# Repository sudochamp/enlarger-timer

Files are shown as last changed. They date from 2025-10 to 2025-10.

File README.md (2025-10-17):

> [!WARNING]
> This project is a work in progress. It functions, but not where I want it yet.

# Darkroom Enlarger Timer

Built to address a simple problem. I just needed a simple timer that could do stop calculations and was accurate enough to be used in a darkroom.

It will need an off-the-shelf AC/DC power supply for the 120/240VAC to 12VDC conversion.

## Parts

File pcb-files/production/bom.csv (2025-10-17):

Designator | Footprint | Quantity | Value | LCSC Part #
C1, C11, C12, C5, C6, C7, C8 | 0603 | 7 | 100n
C10, C9 | 0603 | 2 | 10n
C13 | CP_Elec_4x5.4 | 1 | 10u
C2 | 0603 | 1 | 10u
C3 | 0603 | 1 | 100n | C1525
C4 | 0603 | 1 | 4.7u | C1779
H1, H2, H3, H4 | MountingHole_3.2mm_M3 | 4 | MountingHole
J1 | JST_VH_B2P-VH_1x02_P3.96mm_Vertical | 1 | PWR
J2 | PinHeader_1x04_P2.54mm_Vertical | 1 | SWD
J3 | JST_XH_B3B-XH-A_1x03_P2.50mm_Vertical | 1 | RELAY
R1, R2, R3, R6 | 0603 | 4 | 1k
R4, R5 | 0603 | 2 | 10k
R7 | 0603 | 1 | 51k
SW1 | SW_Kailh_Choc_V2_THT_nSilk | 1 | STOP+
SW2 | SW_Kailh_Choc_V2_THT_nSilk | 1 | STOP-
SW3 | RotaryEncoder_Alps_EC11E-Switch_Vertical_H20mm | 1 | EXPOSURE_TIME
SW4 | SW_Kailh_Choc_V2_THT_nSilk | 1 | TOGGLE
SW5 | Switch_Toggle_SPDT_SubMini | 1 | SW_SPDT
U1 | SOT-223-3_TabPin2 | 1 | LD1117S33TR_SOT223
U2 | LQFP-32_7x7mm_P0.8mm | 1 | STM32C031K6Tx
U3, U4, U5, U6 | SC10-21SURKWA | 4 | SC10-21SURKWA
U7 | SOIC-24W_7.5x15.4mm_P1.27mm | 1 | MAX7221

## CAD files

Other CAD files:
pcb-files/timer_v2.dxf

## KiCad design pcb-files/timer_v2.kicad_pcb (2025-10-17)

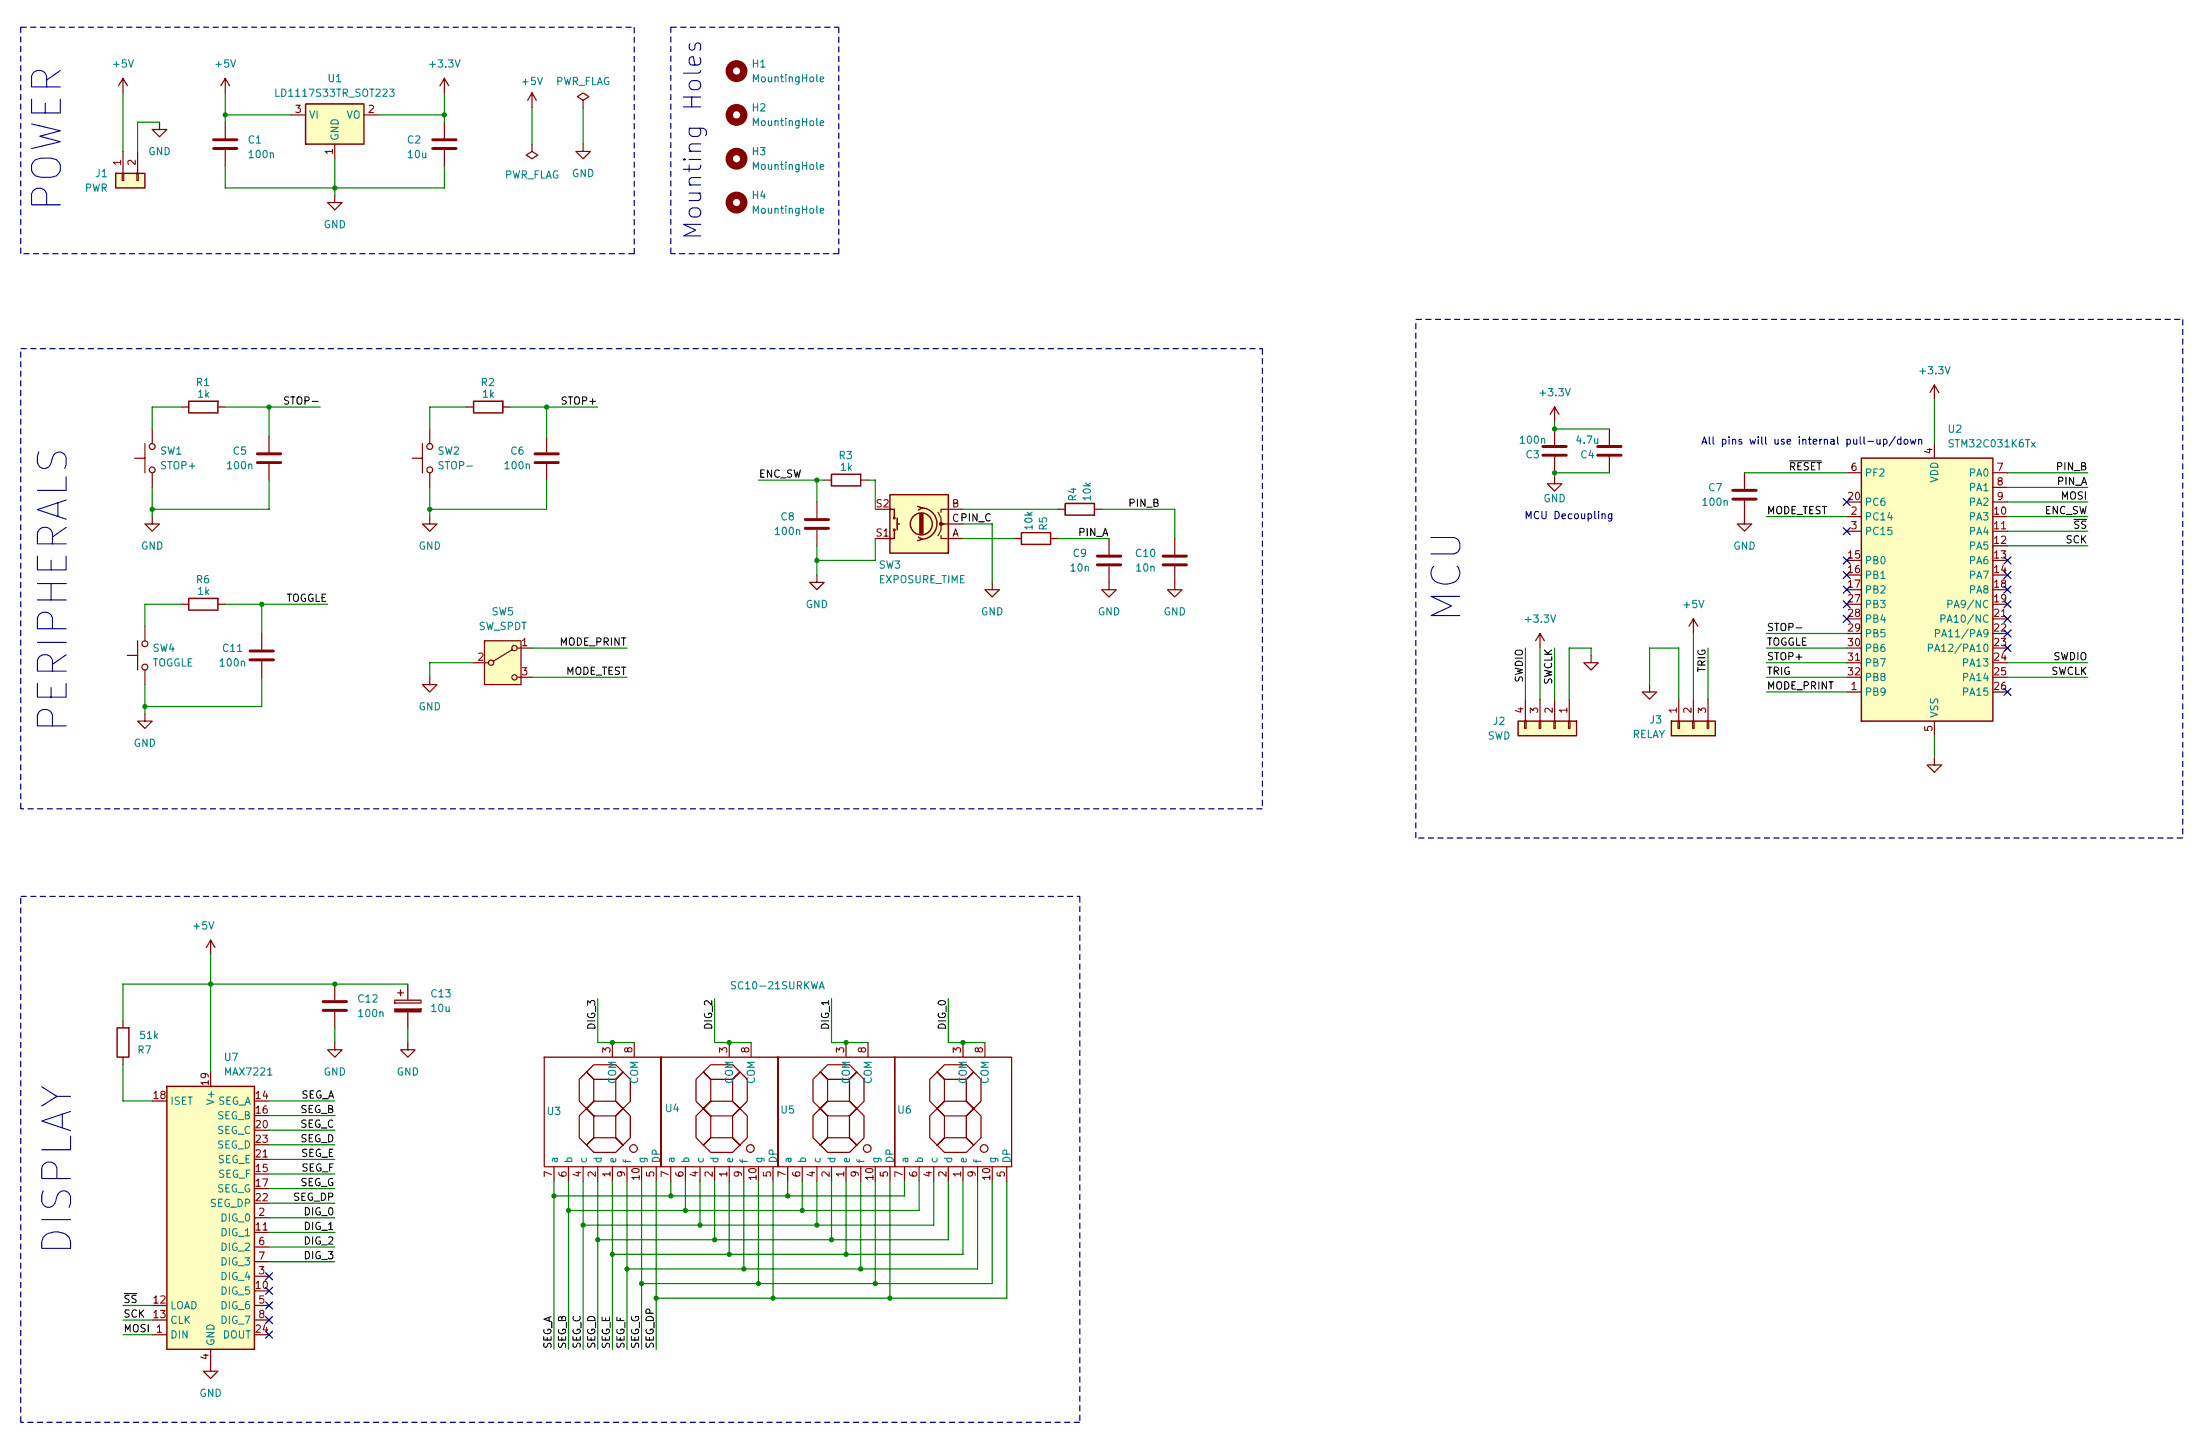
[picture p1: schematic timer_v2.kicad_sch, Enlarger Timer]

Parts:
C1, C8: 100n; C_0603_1608Metric; LCSC Part Number C5299898
C2: 10u; C_0603_1608Metric; LCSC Part Number C5299898
C3: 100n; C_0603_1608Metric; LCSC Part # C1525
C4: 4.7u; C_0603_1608Metric; LCSC Part # C1779
C5, C6, C7, C11, C12: 100n; C_0603_1608Metric; LCSC Part Number C2687355
C9, C10: 10n; C_0603_1608Metric; LCSC Part Number C5299898
C13: 10u; CP_Elec_4x5.4; LCSC Part Number C4747971
H1, H2, H3, H4: MountingHole; MountingHole_3.2mm_M3
J1: PWR; JST_VH_B2P-VH_1x02_P3.96mm_Vertical; LCSC Part Number C158007
J2: SWD; PinHeader_1x04_P2.54mm_Vertical
J3: RELAY; JST_XH_B3B-XH-A_1x03_P2.50mm_Vertical; LCSC Part Number C158007
R1, R2, R3, R6: 1k; R_0603_1608Metric; LCSC Part Number C5123581
R4, R5: 10k; R_0603_1608Metric; LCSC Part Number C5123581
R7: 51k; R_0603_1608Metric; LCSC Part Number C5355236
SW1: STOP+; SW_Kailh_Choc_V2_THT_nSilk; JLCPCB_Footprint SW_Kailh_Choc_V1V2_1.00u
SW2: STOP-; SW_Kailh_Choc_V2_THT_nSilk; JLCPCB_Footprint SW_Kailh_Choc_V1V2_1.00u
SW3: EXPOSURE_TIME; RotaryEncoder_Alps_EC11E-Switch_Vertical_H20mm; JLCPCB_Footprint RotaryEncoder_Alps_EC11E-Switch_Vertica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
SW4: TOGGLE; SW_Kailh_Choc_V2_THT_nSilk; JLCPCB_Footprint SW_Kailh_Choc_V1V2_1.00u
SW5: SW_SPDT; Switch_Toggle_SPDT_SubMini; JLCPCB_Footprint Switch_Toggle_SPDT_Mini_SolderLug
U1: LD1117S33TR_SOT223; SOT-223-3_TabPin2; JLCPCB_Footprint SOT-223-3_TabPin2
U2: STM32C031K6Tx; LQFP-32_7x7mm_P0.8mm; JLCPCB_Footprint LQFP-32_7x7mm_P0.8mm
U3, U4, U5, U6: SC10-21SURKWA
U7: MAX7221; SOIC-24W_7.5x15.4mm_P1.27mm; LCSC Part Number C6705351

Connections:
+3.3V: C2.1, C3.2, C4.2, J2.3, U1.2 (VO), U2.4 (VDD)
+5V: C1.1, C12.1, C13.1, J1.1, J3.2, R7.2, U1.3 (VI), U7.19 (V+)
/DIG_0: U6.3 (COM), U6.8 (COM), U7.2 (DIG_0)
/DIG_1: U5.3 (COM), U5.8 (COM), U7.11 (DIG_1)
/DIG_2: U4.3 (COM), U4.8 (COM), U7.6 (DIG_2)
/DIG_3: U3.3 (COM), U3.8 (COM), U7.7 (DIG_3)
/ENC_SW: C8.2, R3.1, U2.10 (PA3)
/MODE_PRINT: SW5.1 (A), U2.1 (PB9)
/MODE_TEST: SW5.3 (C), U2.2 (PC14)
/MOSI: U2.9 (PA2), U7.1 (DIN)
/PIN_A: C9.2, R5.1, U2.8 (PA1)
/PIN_B: C10.2, R4.2, U2.7 (PA0)
/SCK: U2.12 (PA5), U7.13 (CLK)
/SEG_A: U3.7 (a), U4.7 (a), U5.7 (a), U6.7 (a), U7.14 (SEG_A)
/SEG_B: U3.6 (b), U4.6 (b), U5.6 (b), U6.6 (b), U7.16 (SEG_B)
/SEG_C: U3.4 (c), U4.4 (c), U5.4 (c), U6.4 (c), U7.20 (SEG_C)
/SEG_D: U3.2 (d), U4.2 (d), U5.2 (d), U6.2 (d), U7.23 (SEG_D)
/SEG_DP: U3.5 (DP), U4.5 (DP), U5.5 (DP), U6.5 (DP), U7.22 (SEG_DP)
/SEG_E: U3.1 (e), U4.1 (e), U5.1 (e), U6.1 (e), U7.21 (SEG_E)
/SEG_F: U3.9 (f), U4.9 (f), U5.9 (f), U6.9 (f), U7.15 (SEG_F)
/SEG_G: U3.10 (g), U4.10 (g), U5.10 (g), U6.10 (g), U7.17 (SEG_G)
/STOP+: C6.2, R2.2, U2.31 (PB7)
/STOP-: C5.2, R1.2, U2.29 (PB5)
/SWCLK: J2.2, U2.25 (PA14)
/SWDIO: J2.4, U2.24 (PA13)
/TOGGLE: C11.2, R6.2, U2.30 (PB6)
/TRIG: J3.3, U2.32 (PB8)
/~RESET: C7.2, U2.6 (PF2)
/~SS: U2.11 (PA4), U7.12 (LOAD)
GND: C1.2, C2.2, C3.1, C4.1, C5.1, C6.1, C7.1, C8.1, C9.1, C10.1, C11.1, C12.2, C13.2, J1.2, J2.1, J3.1, SW1.1, SW2.1, SW3.C, SW3.S1, SW4.1, SW5.2 (B), U1.1 (GND), U2.5 (VSS), U7.4 (GND), U7.9 (GND)
unnamed: R1.1, SW1.2
unnamed: R2.1, SW2.2
unnamed: R3.2, SW3.S2
unnamed: R4.1, SW3.B
unnamed: R5.2, SW3.A
unnamed: R6.1, SW4.2
unnamed: R7.1, U7.18 (ISET)

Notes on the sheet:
MCU
MCU Decoupling
Mounting Holes
POWER
All pins will use internal pull-up/down
DISPLAY
PERIPHERALS

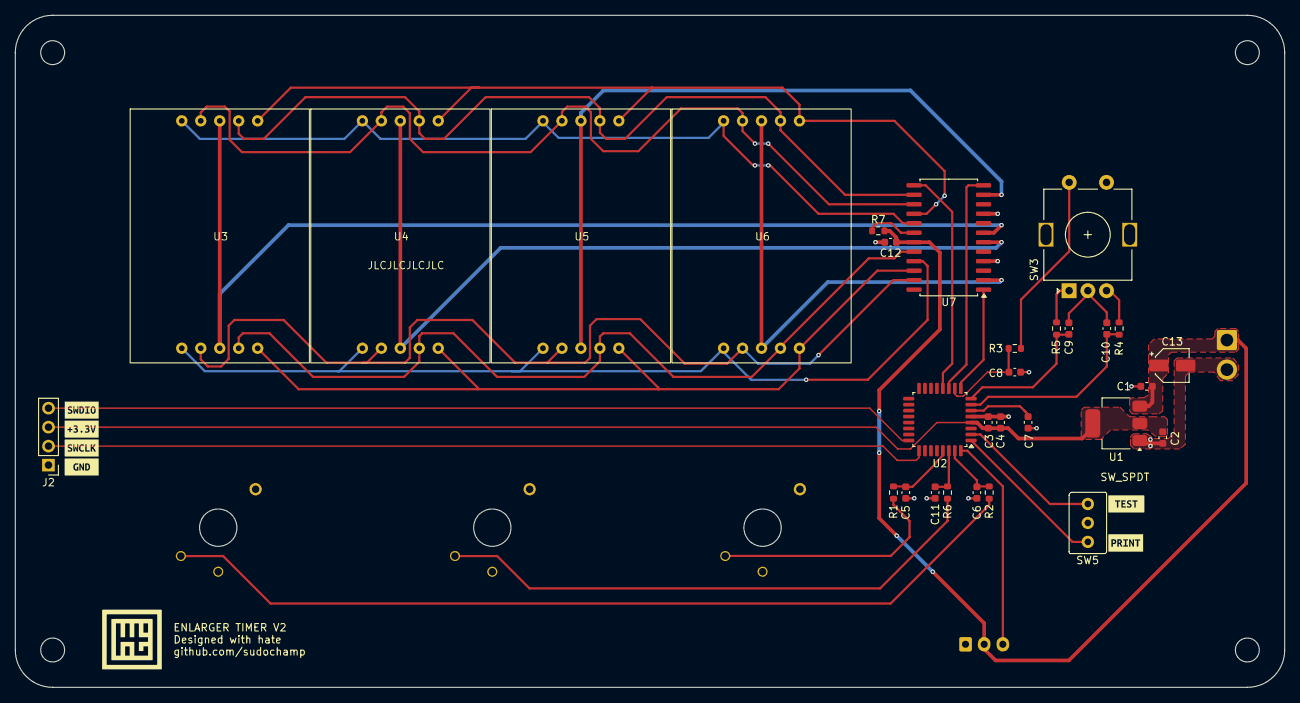
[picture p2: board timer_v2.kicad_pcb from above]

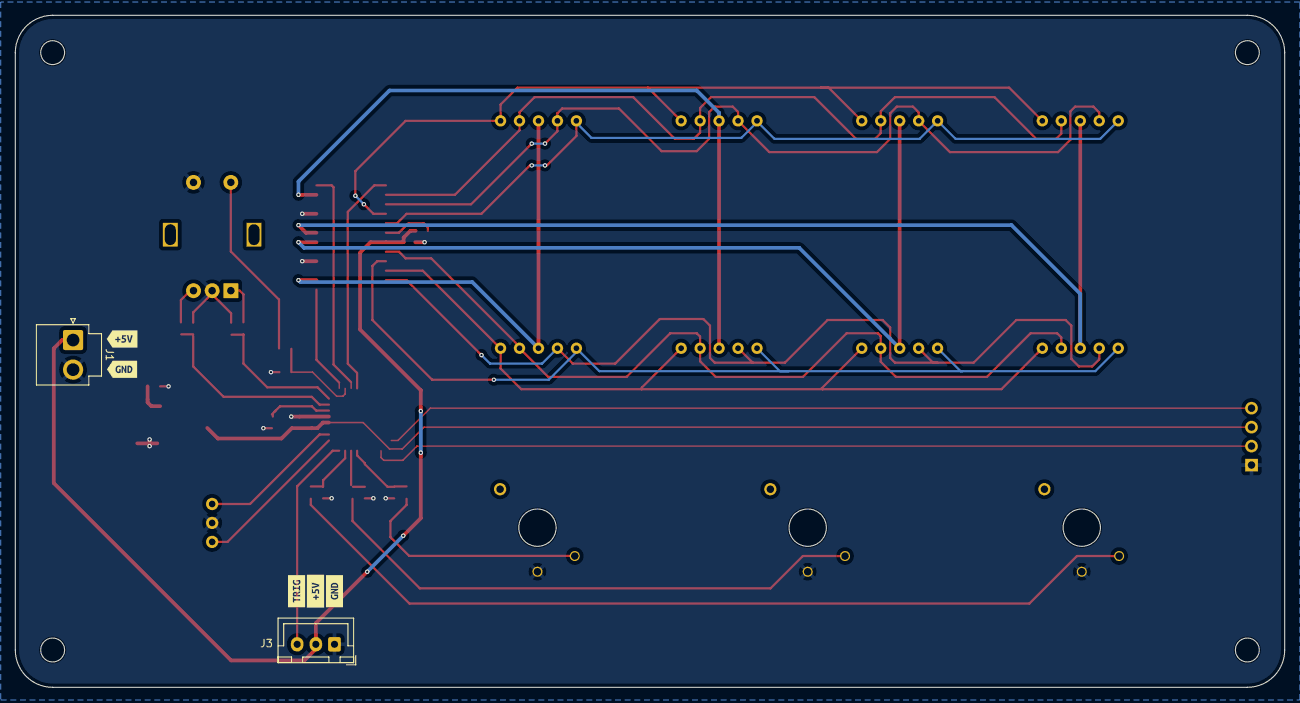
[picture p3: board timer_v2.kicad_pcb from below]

Board: 2 copper layers, 170.0 x 90.0 mm, 50 parts (7 on the bottom side), 37 nets.

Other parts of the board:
kibuzzard-66150B8E: G***; kibuzzard-66150B8E
kibuzzard-66150B83: G***; kibuzzard-66150B83
kibuzzard-66150B89: G***; kibuzzard-66150B89
kibuzzard-66150BA4: G***; kibuzzard-66150BA4
kibuzzard-66150BD0: G***; kibuzzard-66150BD0
kibuzzard-66150C4D: G***; kibuzzard-66150C4D
kibuzzard-66150C9A: G***; kibuzzard-66150C9A
kibuzzard-66150C19: G***; kibuzzard-66150C19
kibuzzard-66150C52: G***; kibuzzard-66150C52
kibuzzard-66150CEE: G***; kibuzzard-66150CEE
kibuzzard-66150D04: G***; kibuzzard-66150D04

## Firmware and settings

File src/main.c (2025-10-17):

#include <stdio.h>
#include <stdlib.h>
#include <avr/io.h>
#include <util/delay.h>
#include <avr/interrupt.h>
#include <math.h>

#include "uart.h"
#include "defines.h"
#include "rotary.h"
#include "max7219.h"

FILE uart_str = FDEV_SETUP_STREAM(uart_putchar, uart_getchar, _FDEV_SETUP_RW);

uint8_t rotary_status;

void Timer0_Start(void)
{
    TCCR0B |= _BV(CS02); // prescaler 256 ~122 interrupts/s
    TIMSK0 |= _BV(TOIE0); // Enable Timer0 Overflow interrupts

    sei(); // Set global interrupts
}

void button_init(void) {
    DDRD &= ~(_BV(PD3)); // set as input
    PORTD |= _BV(PD3); // pullup
}

void calculate_fstops(double seconds, double interval, double *array) {
    // interval = -3;
    // for(int i = 0; i < size; ++i) {
    //     array[i] = seconds * pow(2, (interval + i) * interval
    // }
    array[0] = seconds * pow(2, -3 * interval);
    array[1] = seconds * pow(2, -2 * interval);
    array[2] = seconds * pow(2, -1 * interval);
    array[3] = seconds * pow(2, 0 * interval);
    array[4] = seconds * pow(2, 1 * interval);
    array[5] = seconds * pow(2, 2 * interval);
    array[6] = seconds * pow(2, 3 * interval);
}


void counter_start(int seconds)
{   
    int num = seconds;
    seconds *= 10;
    while (seconds >= 0) {
        MAX7219_displayNumber(seconds);
        _delay_ms(100);
        seconds--;
    }

    MAX7219_displayNumber(num * 10);
}

int main()
{
    init_rotary();
    Timer0_Start();
    uart_init(MYUBRR);
    rotary_reset_status();
    spiMasterInit();
    button_init();

    // Decode mode to "Font Code-B"
    MAX7219_writeData(MAX7219_MODE_DECODE, 0xFF);

    // Scan limit runs from 0.
    MAX7219_writeData(MAX7219_MODE_SCAN_LIMIT, DIGITS_IN_USE - 1);
    MAX7219_writeData(MAX7219_MODE_INTENSITY, 4);
    MAX7219_writeData(MAX7219_MODE_POWER, ON);

    uint8_t rotary_counter, rotary_counter_last = rotary_get_counter();
    uint8_t rotary_status = rotary_get_status();

    stdout = &uart_str;

    fprintf(stdout, "Hello World!\n");

    double arr[6] ={0.0};
    calculate_fstops(5, 0.5, arr);

    MAX7219_displayNumber(arr[5] * 10);

    while (1)
    {
        rotary_counter = rotary_get_counter();
        rotary_status = rotary_get_status();


        if (rotary_counter != rotary_counter_last) { 
            fprintf(stdout, "Counter: %d | Status: %d\n", rotary_counter, rotary_status);
            MAX7219_displayNumber((int) rotary_counter * 10);
            // MAX7219_displayNumber(rotary_counter);
            rotary_counter_last = rotary_counter;
        }

        if (rotary_status == 3) {
            fprintf(stdout, "BUTTON CLICKED!\n");
            counter_start(rotary_counter);
            rotary_reset_status();
        }

        if (!(PIND & _BV(PIND3))) {
            counter_start(rotary_counter);
        }
        
    }

    return 0;
}

ISR(TIMER0_OVF_vect)
{
    // reading rotary and button
    rotary_check_status();
}

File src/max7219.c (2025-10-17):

/* MAX7219 Interaction Code
 * ---------------------------
 * For more information see
 * http://www.adnbr.co.uk/articles/max7219-and-7-segment-displays
 *
 * 668 bytes - ATmega168 - 16MHz
 */
#include <avr/io.h>
#include <util/delay.h>

#include "max7219.h"

// char digitsInUse = 1;

void spiMasterInit (void) {
    // DDRB = (1 << PIN_MOSI) | (1 << PIN_SCK);
    // SPCR = (1 << SPE) | (1 << MSTR) | (1 << SPR0);

    DDRB |= (1 << PIN_SCK) | (1 << PIN_MOSI) | (1 << PIN_SS);
    SPCR |= (1 << SPE) | (1 << MSTR)| (1<<SPR1);
}

void spiSendByte (char databyte)
{
    // Copy data into the SPI data register
    SPDR = databyte;
    // Wait until transfer is complete
    while (!(SPSR & (1 << SPIF)));
}

void MAX7219_writeData(char data_register, char data)
{
    MAX7219_LOAD0;
        // Send the register where the data will be stored
        spiSendByte(data_register);
        // Send the data to be stored
        spiSendByte(data);
    MAX7219_LOAD1;
}

void MAX7219_clearDisplay() 
{
    char i = DIGITS_IN_USE;
    // Loop until 0, but don't run for zero
    do {
        // Set each display in use to blank
        // MAX7219_writeData(i - 1, MAX7219_CHAR_BLANK);
        MAX7219_writeData(i, MAX7219_CHAR_BLANK);
    } while (--i);
}

void MAX7219_displayNumber(volatile long number) 
{
    char negative = 0;

    // Convert negative to positive.
    // Keep a record that it was negative so we can
    // sign it again on the display.
    if (number < 0) {
        negative = 1;
        number *= -1;
    }

    MAX7219_clearDisplay();

    // If number = 0, only show one zero then exit
    if (number == 0) {
        MAX7219_writeData(MAX7219_DIGIT0, 0);
        return;
    }
    
    // Initialization to 0 required in this case,
    // does not work without it. Not sure why.
    char i = 0; 
    
    // Loop until number is 0.
    do {
        // MAX7219_writeData(++i, number % 10);
        MAX7219_writeData(++i, (i == 0x01) ? number % 10 | MAX7219_CHAR_DP : number % 10);
        // Actually divide by 10 now.
        number /= 10;
    } while (number);

    // Bear in mind that if you only have three digits, and
    // try to display something like "-256" all that will display
    // will be "256" because it needs an extra fourth digit to
    // display the sign.
    if (negative) {
        MAX7219_writeData(i, MAX7219_CHAR_NEGATIVE);
    }
}

// int main(void)
// {
//     // SCK MOSI CS/LOAD/SS
//     DDRB |= (1 << PIN_SCK) | (1 << PIN_MOSI) | (1 << PIN_SS);

//     // SPI Enable, Master mode
//     SPCR |= (1 << SPE) | (1 << MSTR)| (1<<SPR1);

//     // Decode mode to "Font Code-B"
//     MAX7219_writeData(MAX7219_MODE_DECODE, 0xFF);

//     // Scan limit runs from 0.
//     MAX7219_writeData(MAX7219_MODE_SCAN_LIMIT, digitsInUse - 1);
//     MAX7219_writeData(MAX7219_MODE_INTENSITY, 8);
//     MAX7219_writeData(MAX7219_MODE_POWER, ON);

//     int i = 999;
//     while(1)
//     {
//         MAX7219_displayNumber(--i);
//         _delay_ms(10);

//         if (i == 0) {
//             i = 999;
//         }
//     }
// }
